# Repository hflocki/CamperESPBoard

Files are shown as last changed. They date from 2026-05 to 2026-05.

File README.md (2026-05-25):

# CamperESP Board

⚠️ **STATUS: WORK IN PROGRESS (In Arbeit)** ⚠️  
*Dieses Projekt befindet sich aktuell noch in der Entwicklung und Testphase. Schaltpläne und Layouts können sich jederzeit ändern. Die Verwendung der Daten erfolgt auf eigene Gefahr.*

---

Das Board basiert auf einem **ESP32** und dient zur flexiblen Erfassung von Sensordaten (z. B. Temperatur, Füllstände) und zur Steuerung von Verbrauchern im Fahrzeug über eine integrierte Transistorschaltstufe.

Das Layout wurde maximal geschrumpft, um perfekt in das ultrakompakte **Spelsberg Mini 25-L/w Gehäuse** (Maße: 89 x 43 x 38 mm) zu passen.

---

## Features

- **Spannungsversorgung:** Robuster Step-Down-Regler (TPS5430) für die raue 12V-Camper-Bordnetzumgebung (mit Sicherung `F1` und Verpolungsschutz `D2`).
- **Kompakte Ausgänge:** 2,54 mm Lochreihen (Pin Header) statt klobiger Klemmen für maximale Platzersparnis und Rüttelfestigkeit.
- **Relais-/Schaltstufe:** Integrierter Transistor (`Q1`) an `GPIO10` zum direkten Schalten kleinerer Verbraucher oder Relais.
- **Schnittstellen:** Voller Hardware-I2C-Bus sowie UART (RX/TX) für die Kommunikation mit Displays, Sensoren oder Victron-Geräten.

---

## Pinbelegung (Pinout)

Die Anschlüsse sind logisch auf zwei einreihige Lochleisten (2,54 mm Raster) am rechten Rand aufgeteilt:

### Leiste 1 (J5) – Stromversorgung & I2C Bus
| Pin | Bezeichnung | Beschreibung |
|:---:|:---|:---|
| 1 | **12V** | Abgesicherter 12V-Ausgang für externe Geräte |
| 2 | **5V** | 5V Versorgungsspannung (VDD) |
| 3 | **3V3** | Saubere 3,3V Logikspannung |
| 4 | **GND** | Gemeinsame Fahrzeugmasse (Minuspol) |
| 5 | **SDA** | I2C Datenleitung (`GPIO4`) |
| 6 | **SCL** | I2C Taktleitung (`GPIO5`) |
| 7 | **G0** | Universal Digital I/O (`GPIO0`) / z.B. OneWire |
| 8 | **G1** | Universal Digital I/O (`GPIO1`) |

### Leiste 2 (J6) – GPIOs & UART
| Pin | Bezeichnung | Beschreibung |
|:---:|:---|:---|
| 1 | **G2** | Universal Digital I/O (`GPIO2`) |
| 2 | **G3** | Universal Digital I/O (`GPIO3`) |
| 3 | **REL** | Relais-Steuerpin (`GPIO10` über Transistorstufe) |
| 4 | **RX** | Serieller Empfangskanal (`GPIO20`) |
| 5 | **TX** | Serieller Sendekanal (`GPIO21`) |
| 6 | *NC* | Frei / Reserve |
| 7 | *NC* | Frei / Reserve |
| 8 | *NC* | Frei / Reserve |

---

## Projektstruktur für GitHub

Dieses Repository enthält alle benötigten KiCad-Quelldateien:

- `CamperESP.kicad_pro` - KiCad Projekt-Hauptdatei
- `CamperESP.kicad_sch` - Schaltplan (Schematic) mit optimiertem Label-Wiring
- `CamperESP.kicad_pcb` - Platinen-Layout (PCB) optimiert für Spelsberg-Gehäuse
- `fp-lib-table` & `sym-lib-table` - Lokale Bibliotheksverweise für benutzte Custom-Bauteile

---

## Einbau- & Löthinweise

1. **Leiterbahnen:** Die Leitungen für `12V`, `5V` und `GND` im Layout mit mindestens **1.0 mm bis 1.5 mm** Breite ausführen, um ausreichende Stromtragfähigkeit im Camper zu gewährleisten.
2. **Kabelanschluss:** Kabel können entweder direkt in die Platinenlöcher eingelötet werden (maximale Rüttelfestigkeit im Fahrbetrieb) oder über eine klassische 2,54 mm Stiftleiste steckbar gemacht werden.

---

## Haftungsausschluss (Disclaimer)

**Haftungsausschluss für Bastler- und DIY-Projekte:**

Die hier bereitgestellten Inhalte, Schaltpläne und Layouts dienen ausschließlich zu Informations- und privaten Bildungszwecken. 

1. **Keine Haftung:** Ich übernehme keinerlei Haftung für Schäden jeglicher Art (einschließlich, aber nicht beschränkt auf Sachschäden, Personenschäden, Fahrzeugbrände oder finanzielle Verluste), die direkt oder indirekt durch den Nachbau, die Nutzung oder Fehlfunktionen dieser Schaltung entstehen.
2. **Eigene Verantwortung:** Das Arbeiten an der Fahrzeugelektrik und Elektronik erfolgt vollständig auf eigene Gefahr und Verantwortung des Ausführenden. 
3. **KFZ-Vorschriften:** Es liegt in der Verantwortung des Nachbauers, für eine fachgerechte Absicherung (Sicherungen, Kabelquerschnitte) zu sorgen und alle geltenden Sicherheitsvorschriften sowie KFZ-Richtlinien einzuhalten.

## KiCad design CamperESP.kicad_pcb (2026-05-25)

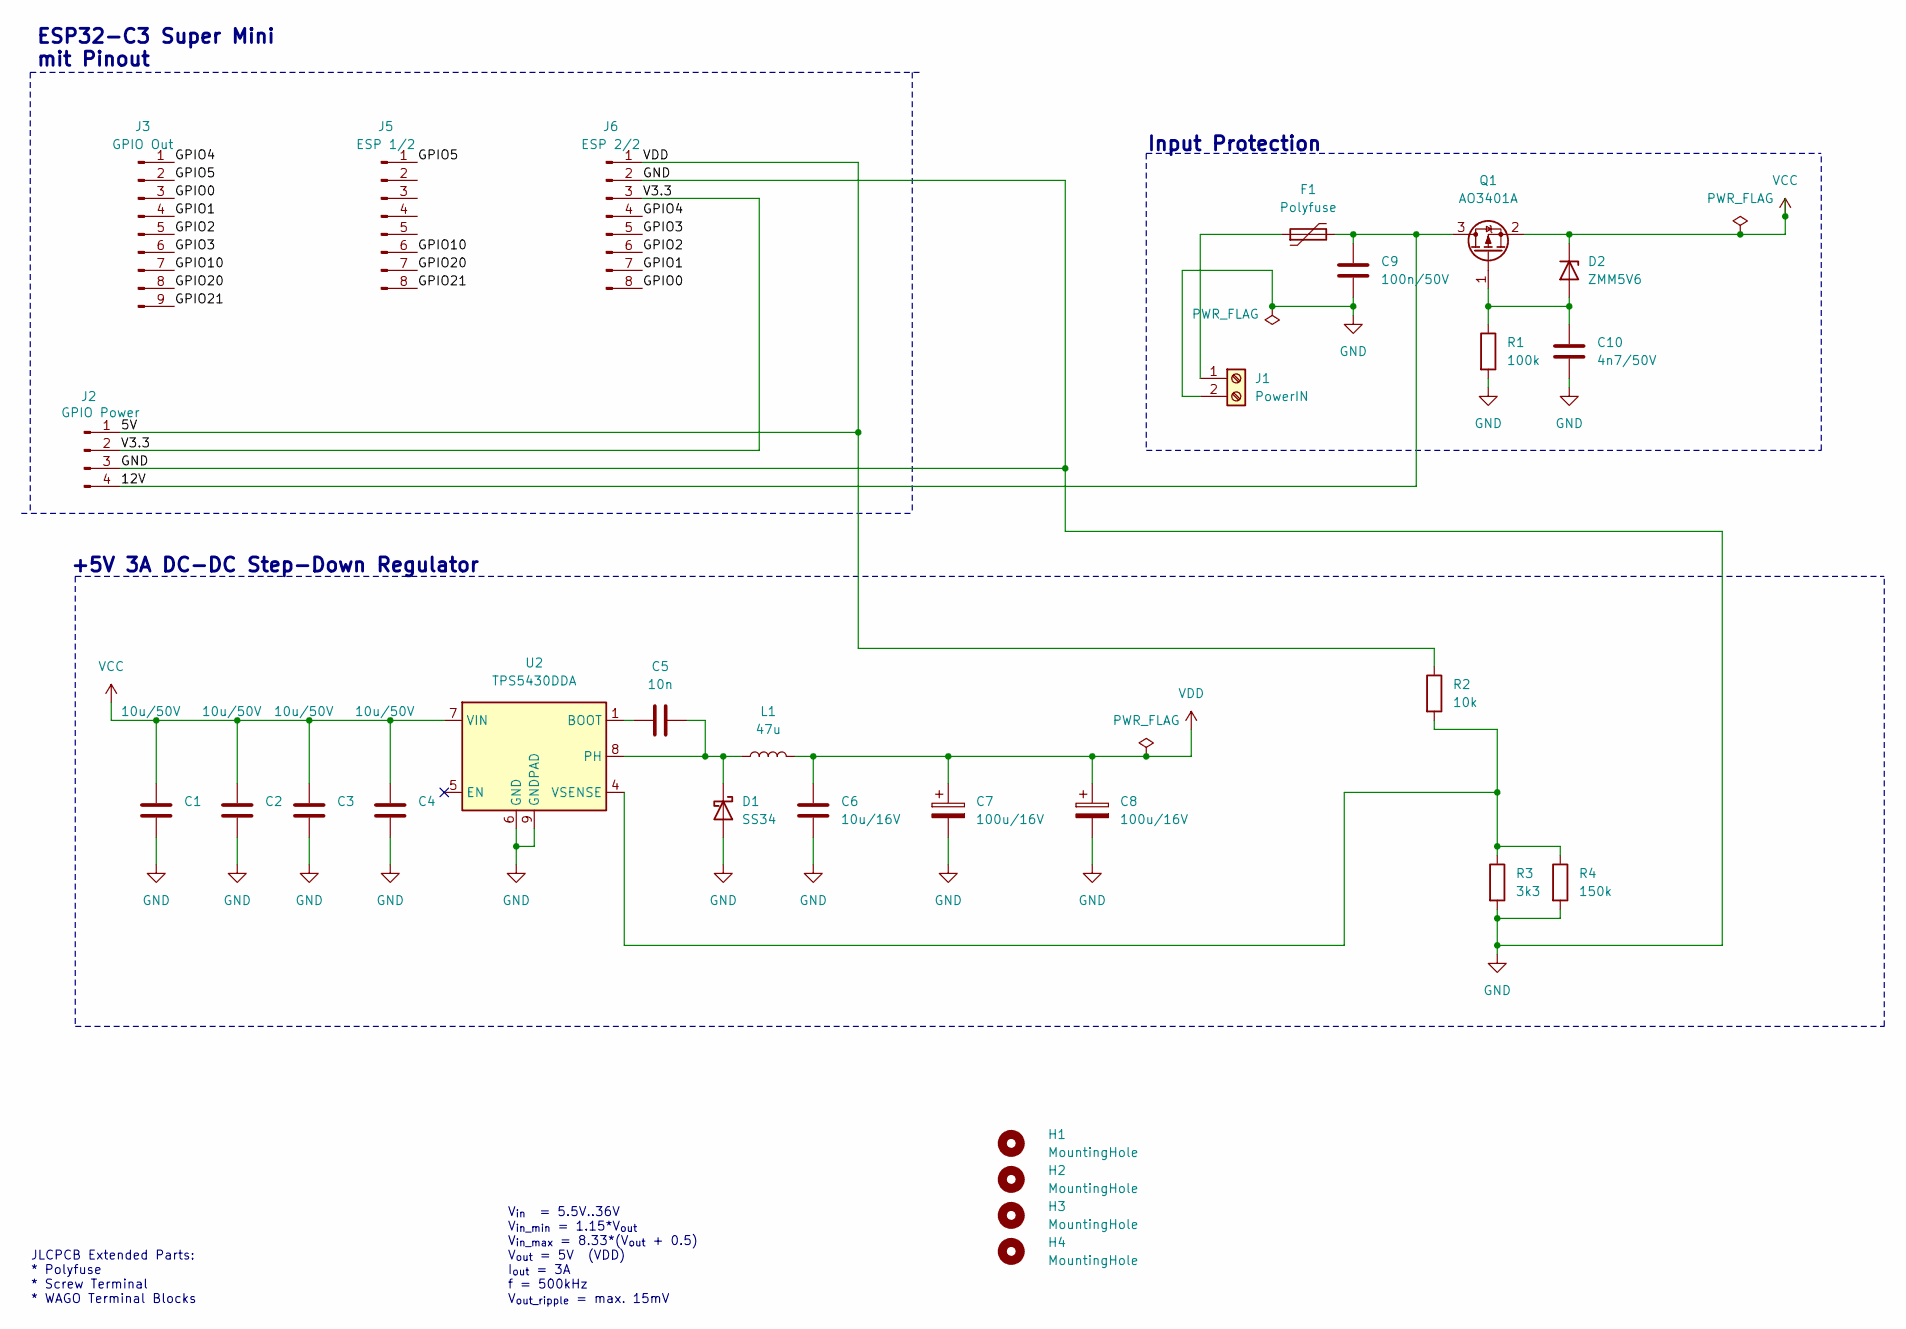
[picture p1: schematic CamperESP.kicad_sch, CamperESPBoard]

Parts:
C1, C2, C3, C4: 10u/50V; C_1206_3216Metric; MPN CL31A106KBHNNNE; LCSC C13585
C5: 10n; C_0402_1005Metric; MPN CL05B103KB5NNNC; LCSC C15195
C6: 10u/16V; C_0402_1005Metric; MPN CL05A106MQ5NUNC; LCSC C15525
C7, C8: 100u/16V; CP_EIA-3528-21_Kemet-B; MPN TAJB107K006RNJ; LCSC C16133
C9: 100n/50V; C_0603_1608Metric; MPN CC0603KRX7R9BB104; LCSC C14663
C10: 4n7/50V; C_0402_1005Metric; MPN 0402B472K500NT; LCSC C1538
D1: SS34; D_SMA; MPN SS34; LCSC C8678
D2: ZMM5V6; D_MiniMELF; MPN ZMM5V6; LCSC C8062
F1: Polyfuse; Fuse_1206_3216Metric; MPN 1206L300SLTHYR; LCSC C207041
H1, H2, H3, H4: MountingHole; MountingHole_2.2mm_M2_ISO7380
J1: PowerIN; TerminalBlock_WAGO_236-102_1x02_P5.00mm_45Degree
J2: GPIO Power; PinHeader_1x04_P2.54mm_Vertical
J3: GPIO Out; PinHeader_1x09_P2.54mm_Vertical
J5: ESP 1/2; PinHeader_1x08_P2.54mm_Vertical
J6: ESP 2/2; PinHeader_1x08_P2.54mm_Vertical
L1: 47u; L_12x12mm_H8mm; MPN MWSA1004S-470MT; LCSC C408491
Q1: AO3401A; SOT-23; MPN AO3401A; LCSC C15127
R1: 100k; R_0402_1005Metric; MPN 0402WGF1003TCE; LCSC C25741
R2: 10k; R_0402_1005Metric; MPN 0402WGF1002TCE; LCSC C25744
R3: 3k3; R_0402_1005Metric; MPN 0402WGF3301TCE; LCSC C25890
R4: 150k; R_0402_1005Metric; MPN 0402WGF1503TCE; LCSC C25755
U2: TPS5430DDA; TI_SO-PowerPAD-8_ThermalVias; MPN TPS5430DDAR; JLC LSOP-8_EP_3.9x4.9x1.27P

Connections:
/12V: C9.1, F1.2, J2.4, Q1.3 (D)
/GPIO0: J3.3, J6.8
/GPIO1: J3.4, J6.7
/GPIO2: J3.5, J6.6
/GPIO3: J3.6, J6.5
/GPIO4: J3.1, J6.4
/GPIO5: J3.2, J5.1
/GPIO10: J3.7, J5.6
/GPIO20: J3.8, J5.7
/GPIO21: J3.9, J5.8
/V3.3: J2.2, J6.3
GND: C1.2, C2.2, C3.2, C4.2, C6.2, C7.2, C8.2, C9.2, C10.2, D1.2 (A), J1.2, J2.3, J6.2, R1.2, R3.2, R4.2, U2.6 (GND), U2.9 (GNDPAD)
unnamed: C5.2, D1.1 (K), L1.1, U2.8 (PH)
unnamed: C10.1, D2.2 (A), Q1.1 (G), R1.1
unnamed: F1.1, J1.1
unnamed: C5.1, U2.1 (BOOT)
unnamed: R2.2, R3.1, R4.1, U2.4 (VSENSE)
VCC: C1.1, C2.1, C3.1, C4.1, D2.1 (K), Q1.2 (S), U2.7 (VIN)
VDD: C6.1, C7.1, C8.1, J2.1, J6.1, L1.2, R2.1

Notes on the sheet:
V_{in} = 5.5V..36V V_{in_min} = 1.15*V_{out} V_{in_max} = 8.33*(V_{out} + 0.5) V_{out} = 5V (VDD) I_{out} = 3A f = 500kHz V_{out_ripple} = max. 15mV
Input Protection
ESP32-C3 Super Mini mit Pinout
JLCPCB Extended Parts: * Polyfuse * Screw Terminal * WAGO Terminal Blocks
+5V 3A DC-DC Step-Down Regulator

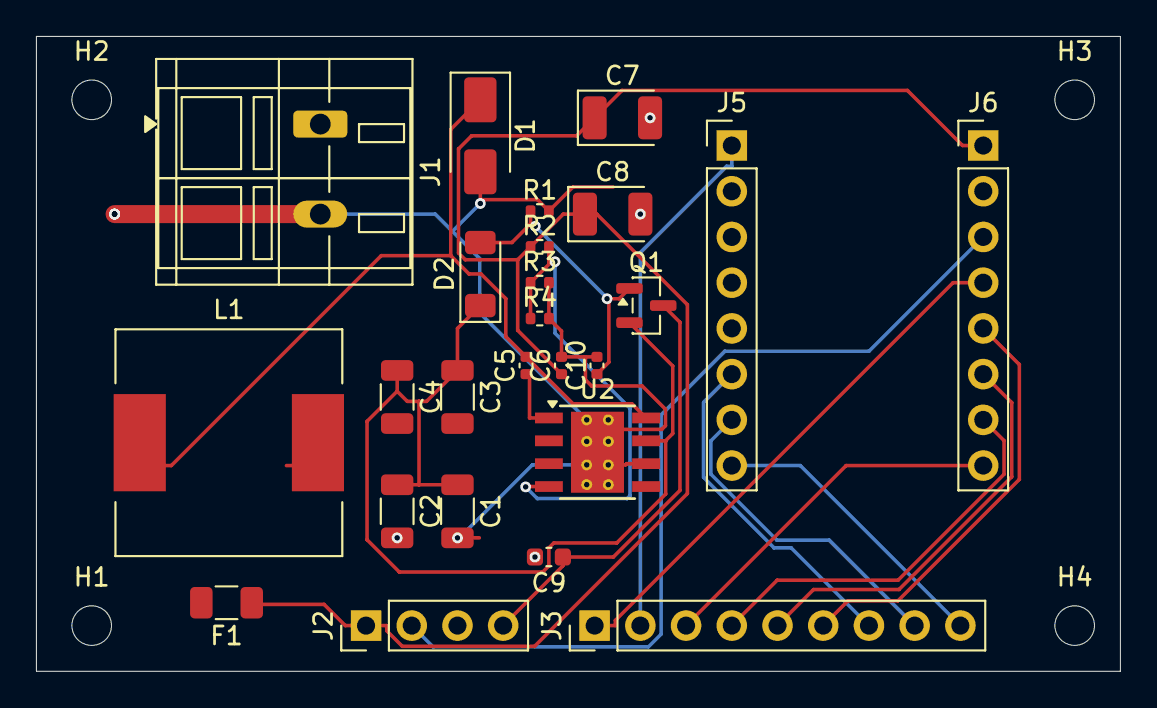
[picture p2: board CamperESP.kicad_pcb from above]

Board: 2 copper layers, 60.2 x 35.3 mm, 29 parts (0 on the bottom side), 19 nets.
